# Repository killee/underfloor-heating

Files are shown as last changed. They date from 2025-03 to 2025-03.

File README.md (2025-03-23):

# Underfloor Heating Controller with ESPHome

This project is designed to control an underfloor heating system using an ESP32 running ESPHome. The system connects an ESP32 with a relay board (or, preferably, SSRs) to control the heating valves of a floor heating system. By reusing the pre-existing wiring for Dallas temperature sensors, each room can continuously report its current temperature. The climate device then uses this data to manage heating.

## Features
- Control of underfloor heating via an ESP32 connected to a relay/SSR board.
- Utilization of Dallas temperature sensors with existing wiring.
- Two-point regulation strategy: optimized for the inherent sluggish response of underfloor heating.
- Fully standalone operation on the ESP, ensuring continued performance even if Home Assistant is offline.
- A modular configuration structure optimized for multi-storey buildings, avoiding repetitive configuration across floors.

## Configuration Structure
- **underfloorheating.yaml**: The main configuration file that sets substitutions, ESP settings, sensors, and includes common packages.
- **common/\***: Contains modular YAML files:
   - `sensor_generic.yaml`: Common sensor settings.
   - `network_generic.yaml`: Network settings including WiFi and OTA configuration.
   - `underfloor_heating_termostat.yaml`: Common thermostat settings for the heating control.
   - `underfloor_heating_generic.yaml`: Configuration for the climate devices and switches controlling the heating valves.
- **LICENSE**: Contains the GNU General Public License for the project.

## Setup & Installation
1. Flash the ESP32 with the provided ESPHome configuration.
2. Connect the ESP32 to a relay board or SSRs and interface it with the heating valves.
   - The controller board is housed in the large enclosure shown in the image of the heating manifold.
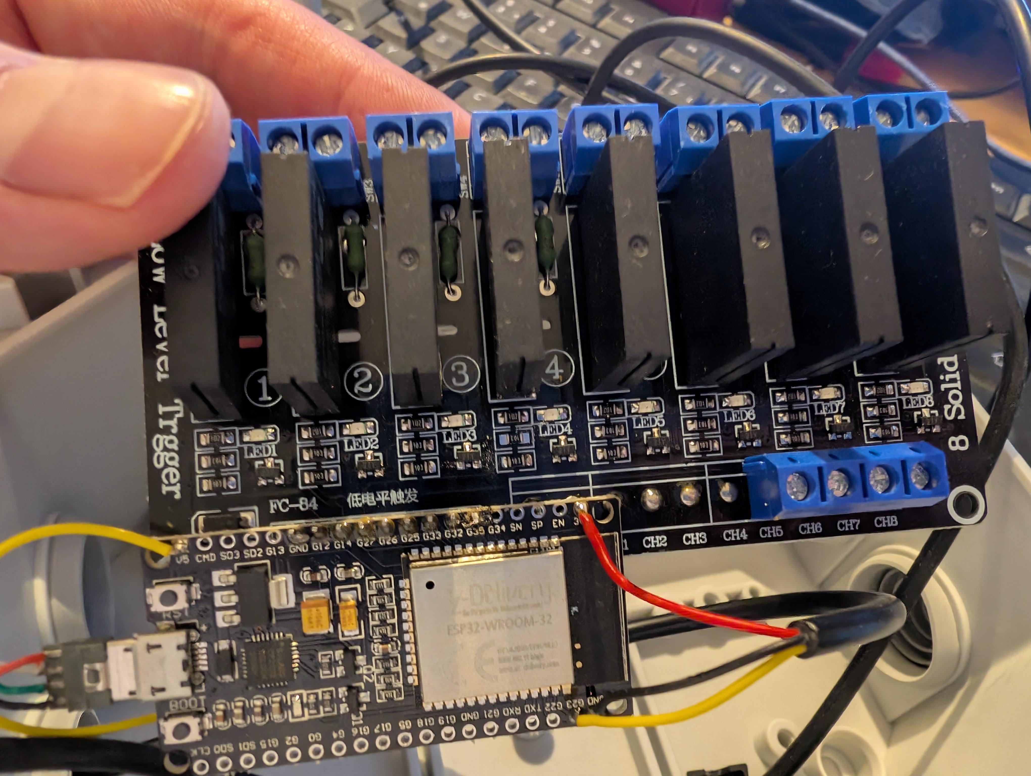
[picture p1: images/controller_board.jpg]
Controller Board with SSR relais
   
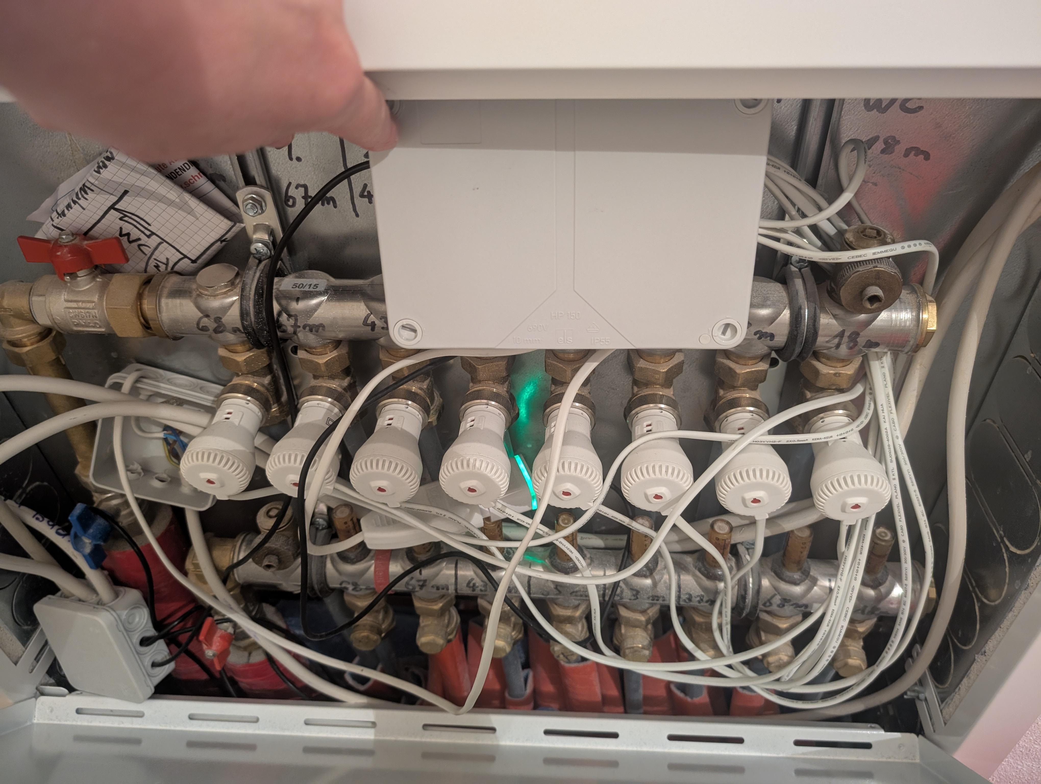
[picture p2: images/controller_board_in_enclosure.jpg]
Controller Board in Enclosure
   
3. Install Dallas temperature sensors using the existing wiring in your building.
   - The temperature sensors are all connected in the additional junction box with the Wago connectors.
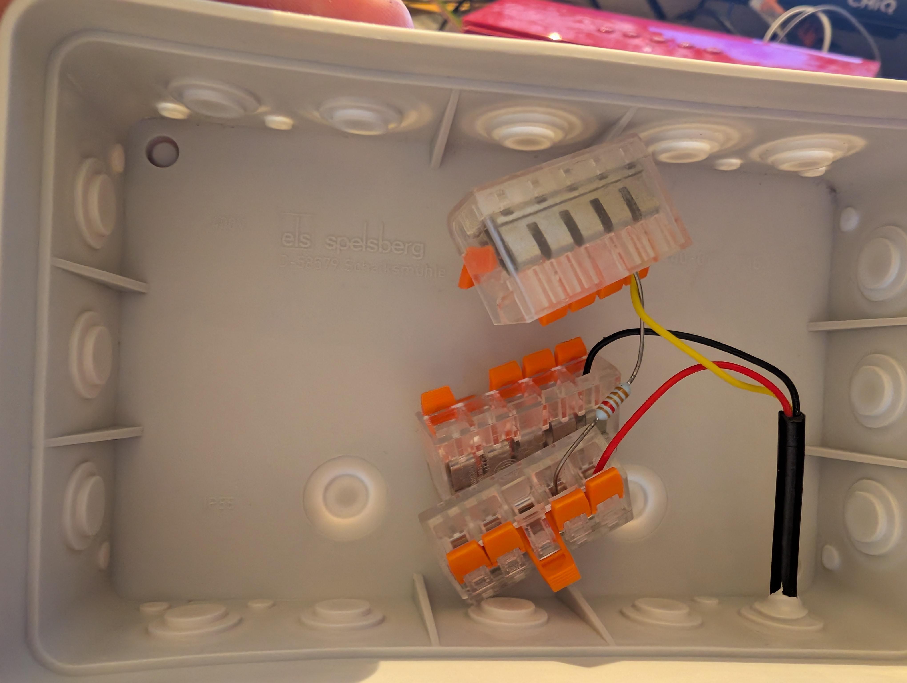
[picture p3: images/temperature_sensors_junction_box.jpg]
Temperature Sensors Junction Box
   
   - To obtain the OneWire sensor addresses, connect one sensor at a time. Then, check the ESPHome logs for the sensor's ID and assign it to the corresponding room in your configuration. Repeat this process for each sensor.
4. Adjust network settings and substitutions in `underfloorheating.yaml` to match your environment.
5. Start the system and enjoy a smart, efficient, and cost-effective heating solution!
   - The USB power supply for the controller board can be seen glowing in the image of the heating manifold.

## Hardware
The hardware required for this project is very cost-effective, with a total cost of under 50€. The main components include:
- ESP32 microcontroller
- Relay board or SSRs
- Dallas temperature sensors
- 5V USB power supply
- some Wagos + installation material

Additionally, a printable cover (`UP-Dose Abdeckung.stl`) is available, which fits standard German wall boxes and includes a holder for the OneWire sensors.

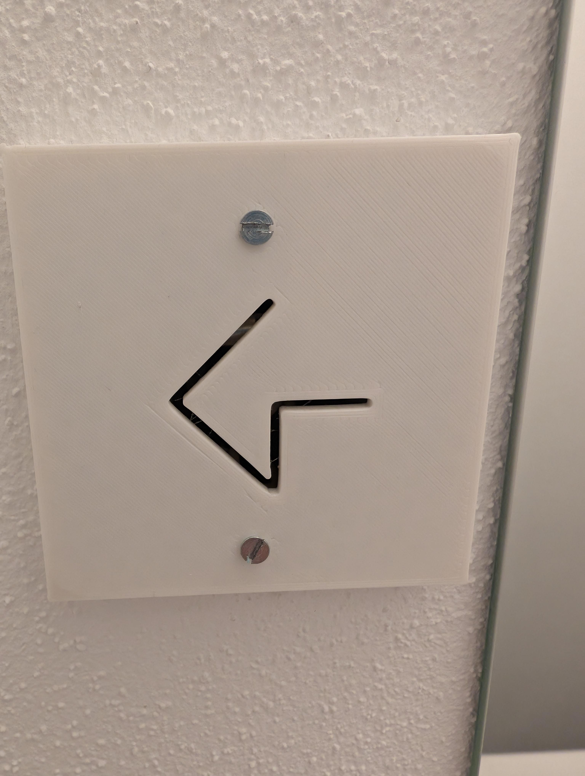
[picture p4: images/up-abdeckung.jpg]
UP-Dose Abdeckung


## Visual Representation

### Heating Temperature Graph
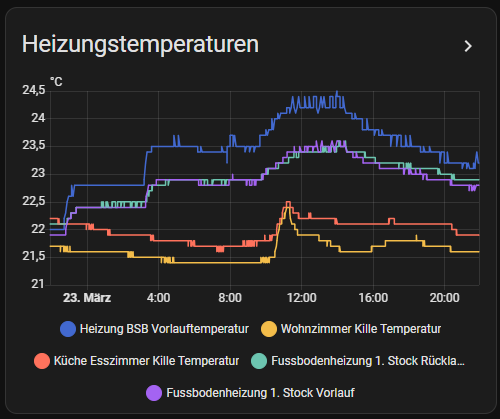
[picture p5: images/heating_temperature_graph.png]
Heating Temperature Graph


### Control Panel
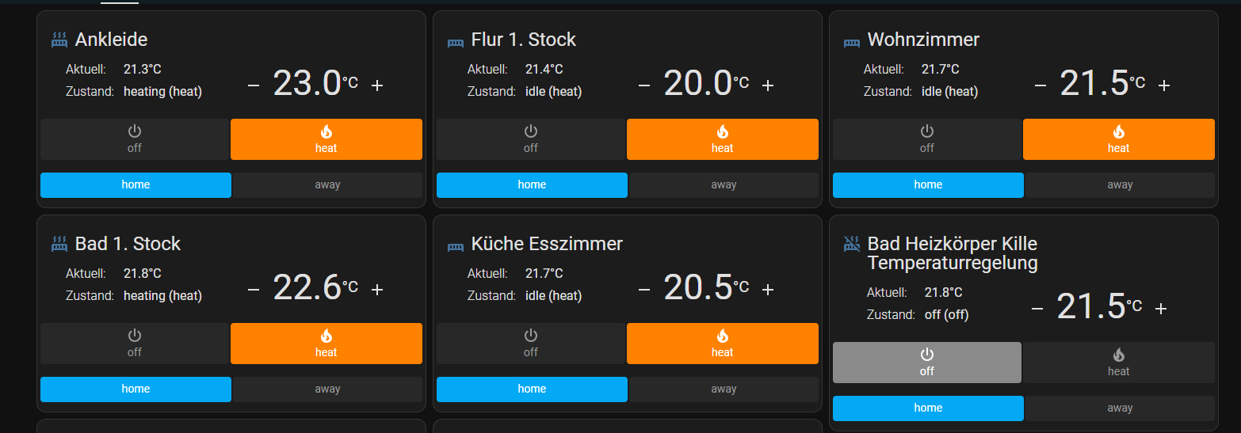
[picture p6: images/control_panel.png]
Control Panel


## Notes
If you need any clarifications or further information, please ask.

Happy heating control!

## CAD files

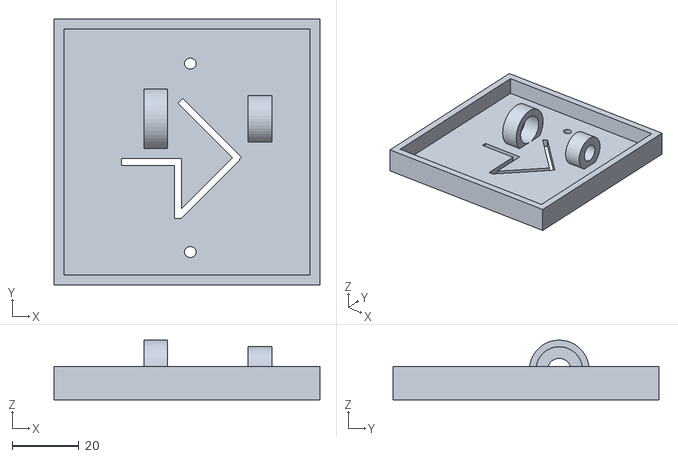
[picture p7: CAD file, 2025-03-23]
UP-Dose Abdeckung.stl
80.0 x 80.0 x 18.0

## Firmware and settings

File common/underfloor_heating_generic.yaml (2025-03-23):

climate:
  - platform: thermostat
    id: room1_thermostat
    name: ${room1} Temperaturregelung         # Thermostat control for room1
    sensor: room1_temp                         # Uses temperature sensor for room1
    <<: !include underfloor_heating_termostat.yaml  # Common thermostat settings
    heat_action:
      - switch.turn_on: room1_output           # Turn on heating valve for room1
    idle_action:
      - switch.turn_off: room1_output          # Turn off heating valve for room1

  - platform: thermostat
    id: room2_thermostat
    name: ${room2} Temperaturregelung         # Thermostat control for room2
    sensor: room2_temp                         # Uses temperature sensor for room2
    <<: !include underfloor_heating_termostat.yaml
    heat_action:
      - switch.turn_on: room2_output           # Turn on heating valve for room2
    idle_action:
      - switch.turn_off: room2_output          # Turn off heating valve for room2

  - platform: thermostat
    id: room3_thermostat
    name: ${room3} Temperaturregelung         # Thermostat control for room3
    sensor: room3_temp                         # Uses temperature sensor for room3
    <<: !include underfloor_heating_termostat.yaml
    heat_action:
      - switch.turn_on: room3_output           # Turn on heating valve for room3
    idle_action:
      - switch.turn_off: room3_output          # Turn off heating valve for room3

  - platform: thermostat
    id: room4_thermostat
    name: ${room4} Temperaturregelung         # Thermostat control for room4
    sensor: room4_temp                         # Uses temperature sensor for room4
    <<: !include underfloor_heating_termostat.yaml
    heat_action:
      - switch.turn_on: room4_output           # Turn on heating valve for room4
    idle_action:
      - switch.turn_off: room4_output          # Turn off heating valve for room4

  - platform: thermostat
    id: room5_thermostat
    name: ${room5} Temperaturregelung         # Thermostat control for room5
    sensor: room5_temp                         # Uses temperature sensor for room5
    <<: !include underfloor_heating_termostat.yaml
    heat_action:
      - switch.turn_on: room5_output           # Turn on heating valve for room5
    idle_action:
      - switch.turn_off: room5_output          # Turn off heating valve for room5

  - platform: thermostat
    id: room6_thermostat
    name: ${room6} Temperaturregelung         # Thermostat control for room6
    sensor: room6_temp                         # Uses temperature sensor for room6
    <<: !include underfloor_heating_termostat.yaml
    heat_action:
      - switch.turn_on: room6_output           # Turn on heating valve for room6
    idle_action:
      - switch.turn_off: room6_output          # Turn off heating valve for room6

  - platform: thermostat
    id: room7_thermostat
    name: ${room7} Temperaturregelung         # Thermostat control for room7
    sensor: room7_temp                         # Uses temperature sensor for room7
    <<: !include underfloor_heating_termostat.yaml
    heat_action:
      - switch.turn_on: room7_output           # Turn on heating valve for room7
    idle_action:
      - switch.turn_off: room7_output          # Turn off heating valve for room7

switch:
  - platform: gpio
    pin: 12 #18
    inverted: True
    name: ${devicename} on                     # Main device power indicator/control
  - platform: gpio
    pin: 14 #25
    id: room1_output
    inverted: True                           # Controls heating valve for room1
  - platform: gpio
    pin: 27 #26
    id: room2_output
    inverted: True                           # Controls heating valve for room2
  - platform: gpio
    pin: 26 #27
    id: room3_output
    inverted: True                           # Controls heating valve for room3
  - platform: gpio
    pin: 25 #22
    id: room4_output
    inverted: True                           # Controls heating valve for room4
  - platform: gpio
    pin: 33 #21
    id: room5_output
    inverted: True                           # Controls heating valve for room5
  - platform: gpio
    pin: 32 #19
    id: room6_output
    inverted: True                           # Controls heating valve for room6
  - platform: gpio
    pin: 13 #17
    id: room7_output
    inverted: True                           # Controls heating valve for room7

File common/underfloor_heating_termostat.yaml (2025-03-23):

heat_deadband: 0.2 °C          # Minimum temperature difference to trigger heating adjustments
heat_overrun: 0.2 °C           # Additional tolerance to avoid rapid switching
min_idle_time: 5min            # Shortest period the system remains idle
min_heating_off_time: 5min     # Minimum time between heating cycles when off
min_heating_run_time: 5min     # Minimum time the heating stays on per cycle
#default_mode: "heat"          # Uncomment to force a default heating mode if needed
default_preset: Home           # Default preset is 'Home'

preset:
  - name: Home
    default_target_temperature_low: 20 °C   # Target temperature in Home preset
  - name: Away
    default_target_temperature_low: 18 °C   # Lower target when in Away preset
    mode: heat                              # Heating mode override for Away

visual:
  min_temperature: 14 °C      # Minimum temperature displayed on UI
  max_temperature: 26 °C      # Maximum temperature displayed on UI
  temperature_step: 0.1 °C    # Increment step for temperature adjustments

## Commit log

2025-03-23 Add configuration files for underfloor heating system and related sensors
2025-03-23 Enhance README with hardware details and visual aids; add image processing script to remove metadata
    [UP-Dose Abdeckung.stl]
2025-03-23 Add images of controller board and temperature sensors to README
